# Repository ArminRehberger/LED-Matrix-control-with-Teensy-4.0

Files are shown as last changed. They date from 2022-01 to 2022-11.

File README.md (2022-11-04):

# LEDMatrix-control-with-Teensy-4.0

LED matrix control with Teensy 4.0

Video:  
https://www.youtube.com/watch?v=ZAkksoPda_Q

Functional description:  
FunctionDescriptionLEDMatrix_V1_00.pdf  
FunctionDescriptionLED.pdf  

Implementation of a LED matrix control.
Four LED-Matrix with each 8x32 pixel
Each matrix with 256 pixels, all together 1024 pixel.

Schematic diagram KiCad:


Disclaimer:  
This hardware/software is provided "as is", and you use the hardware/software at your own risk. Under no circumstances shall any author be liable for direct, indirect, special, incidental, or consequential damages resulting from the use, misuse, or inability to use this hardware/software, even if the authors have been advised of the possibility of such damages

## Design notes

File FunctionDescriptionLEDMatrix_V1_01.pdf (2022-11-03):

Function description for LED Matrix, V1.01 2022-11-03, Armin Rehberger

## Table of content

## General description

Implementation of a LED matrix control.
Four LED-Matrix with each 8x32 pixel
Each matrix with 256 pixels, all together 1024 pixel.

Type LED-Matrix: BTF-LIGHTING WS2812BECO https://www.amazon.de/gp/product/B088K1KDW5/ref=ppx_od_dt_b_asin_title_s00?ie=UTF8&psc=1 (https://www.amazon.de/gp/product/B088K1KDW5/ref=ppx_od_dt_b_asin_title_s00?ie=UTF8&psc=1)

## Used hardware

Teensy 4.0

## Used software

Teensy 4.0
Arduino 1.8.15
Teensy Loader 1.54

## Principle structure

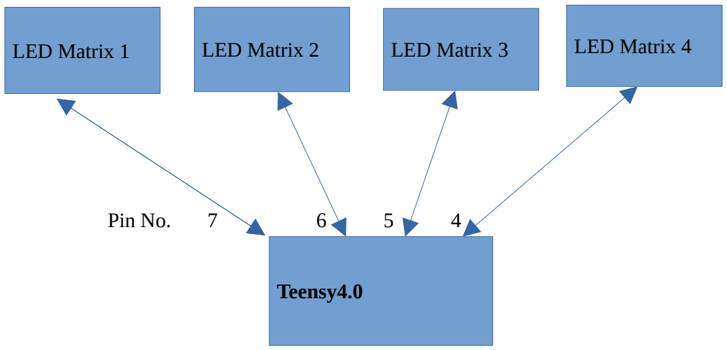
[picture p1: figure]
Pin No.; Teensy4.0; LED Matrix 1; LED Matrix 2; LED Matrix 3; LED Matrix 4

## Used libarys

Libary for LEDs driver: OctoWS2811 https://github.com/PaulStoffregen/OctoWS2811 OctoWS2811.h

Libary for color and shift the LEDs LEDMatrix8.h

## Frequency calculation

Example RGB LED strip with 256LEDs 800Khz = 1.25us
Per bit (high or low): 1.25us
Per LED: 3 Byte = 24 Bit = 30us
Reset: 50us
Per 256 LED: 30us * 256LED = 7680us + 50us = 7730us = 7.73ms Frequency: F=1/t = 1/0.00773s = 129.36Hz

## Software

Already defined letters in function "InitializeLetters" "ABCDEFGHIJKLMNOPQRSTUVWXYZ1234567890!?.:+-=# {}[]" { Haert, part 1
} Haert, part 2
[ Smily, part 1
] Smily, part 2

A string array „char StringToDraw[3][4000]“ must be initialized with the strings to draw. char StringToDraw[3][4000] = {
" [][][][]{}{}{}{} ",
"MERRY CHRISTMAS AND A HAPPY NEW YEAR {}{} ",
"FROHE WEIHNACHTEN UND EIN GUTES NEUES JAHR [][] ", };
The string char array must not exceed 1773 characters.

Scenes
The struct ParaDraw for 100 scenes is foreseen. These struct must be initialized.

ArrayIndexUsed: Must be true, when the scene should be drawen
StringNo: String no. in the StringToDraw array to be drawen
DelaytimeMillis: Delaytime in ms to shift the pixel array e.g. 10, 20, 25, 50, 100, 2000, 0=fastest possible speed
ColorSceneNo: COLOR0, whole matrix one times BLUE, then one times GREEN, then one times RED, ...YELLOW PINK ORANGE WHITE
ColorSceneNo: COLOR1, whole matrix blue MinIntense..MaxIntense..MinIntense, green MinIntense..MaxIntense..MinIntense, red MinIntense..MaxIntense..MinIntense ColorSceneNo: COLOR2, whole matrix in value Color
Color: Used for COLOR2. RED, GREEN, BLUE, YELLOW, PINK, ORANGE, WHITE, BACKGROUNDCOLUR
MaxIntense: Used for Color1, MaxIntense 0..255. MinIntense = 1
AnimationNo: NONE, LEFT, RIGHT, UP, DOWN
AmountNo: Show string x times, e.g. LEFT 7 times

Example:
ParaDraw[Index].ArrayIndexUsed = true; ParaDraw[Index].StringNo = 1; ParaDraw[Index].DelaytimeMillis = 20; ParaDraw[Index].ColorSceneNo = COLOR2; ParaDraw[Index].Color = BLUE; // Just for COLOR2 ParaDraw[Index].MaxIntense = 96; // Just for COLOR1 ParaDraw[Index].AnimationNo = LEFT; ParaDraw[Index].AmountNo = 2;

## Input / Output assignment Teensy 4.0

Pin | Used for
13 | LED buildin
14 | Reserve
15 | Reserve
16 | Reserve
17 | Reserve
18 | SDA0 Reserve
19 | SCL0 Reserve
20 | Reserve
21 | Reserve
22 | Reserve
23 | Reserve
3.3V | Output 250mA (Not connected)
GND 0V Power supply 0V
Vin 5V | Power supply 5V
12 | Reserve
11 | Reserve
10 | Reserve
9 | Reserve
8 | Reserve
7 | LED matrix 1 (Output)
6 | LED matrix 2 (Output)
5 | LED matrix 3 (Output)
4 | LED matrix 4 (Output)
3 | LED matrix 5 (Output)
2 | LED matrix 6 (Output)
1 | LED matrix 7 (Output)
0 | LED matrix 8 (Output)
GND 0V (Not connected)

## KiCad

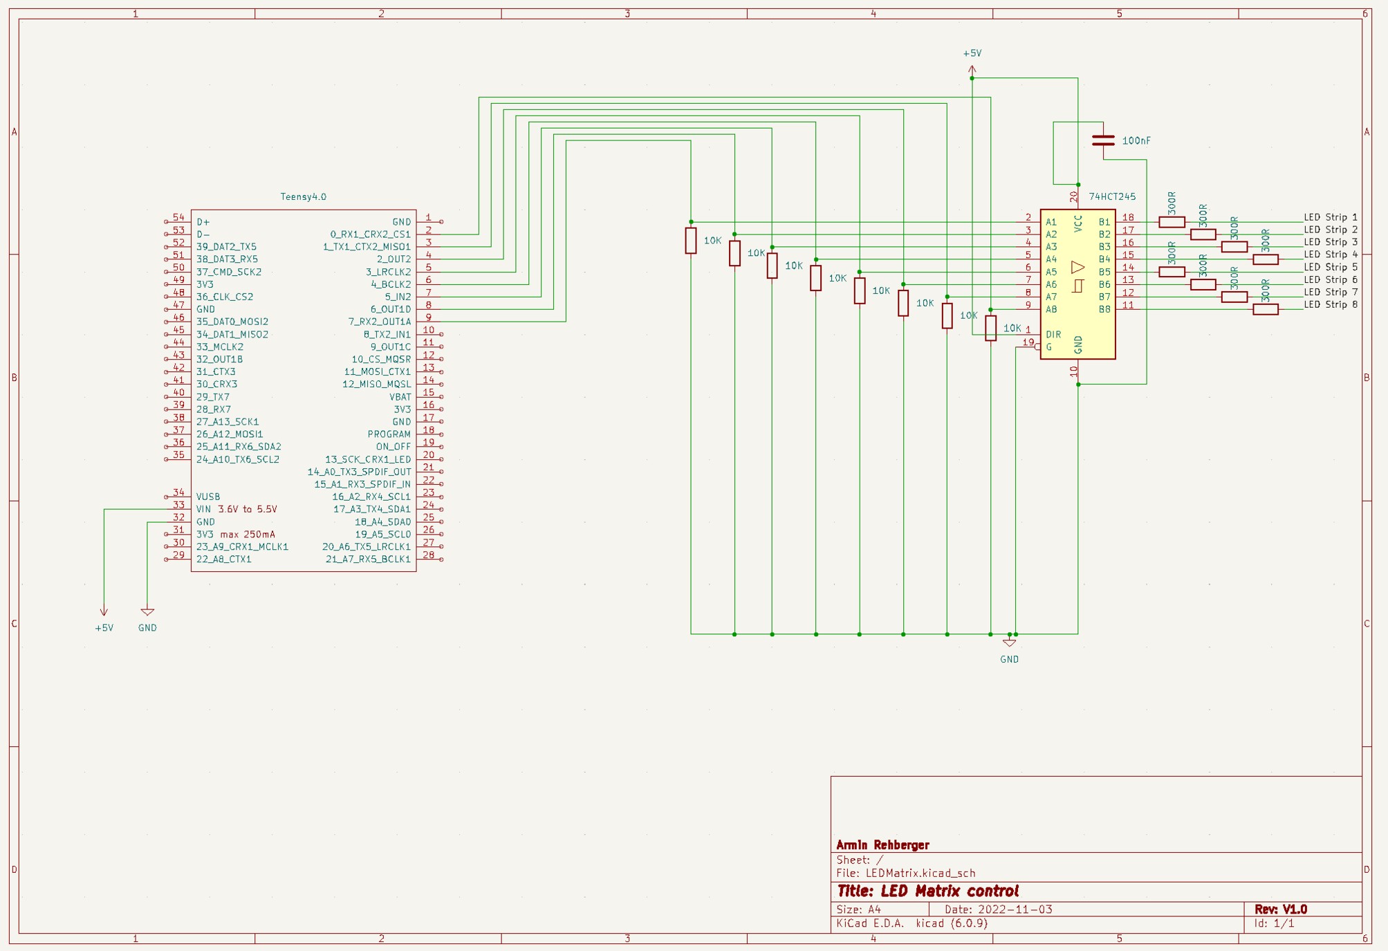
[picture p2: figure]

## Layout circuit board Teensy 4.0

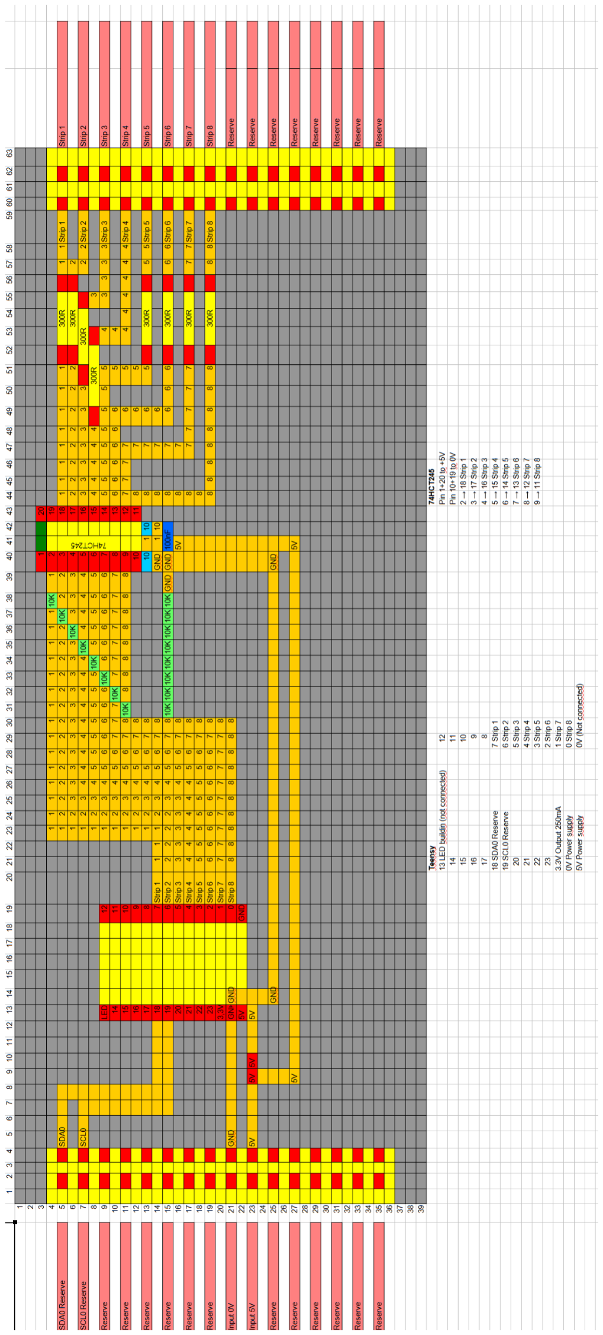
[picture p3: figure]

## Pictures

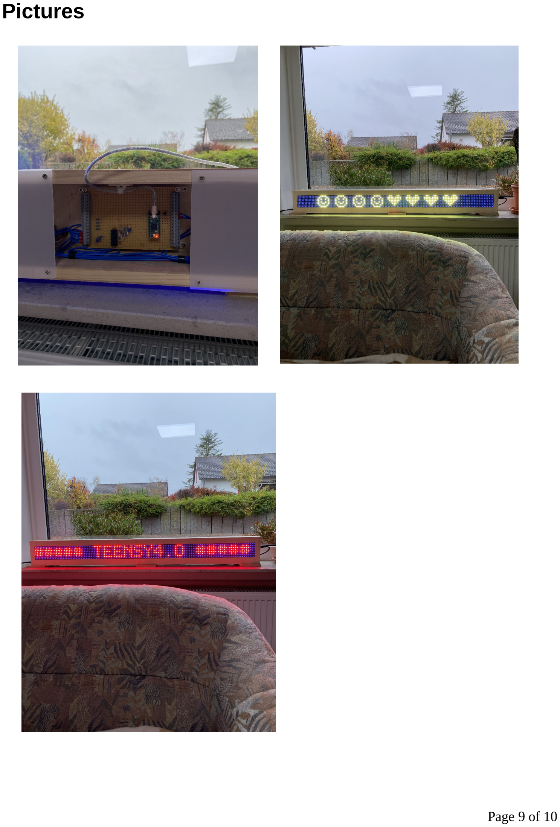
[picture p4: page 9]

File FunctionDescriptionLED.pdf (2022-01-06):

### ProgramFunctions

### Seite 1

byte***drawingLetters; // Three-dimensional array for all letters (level), each letter has 8 line and 6 column (line vertical, column horizontal) void LEDMatrix8::InitializeLetters
First letter
Column → | Example T

← Line

0/0/0 | 0/0/1 | 0/0/2 | 0/0/3 | 0/0/4 | 0/0/5 | 1 | 1 | 1 | 1 | 1 | 0
0/1/0 | 0/1/1 | 0/1/2 | 0/1/3 | 0/1/4 | 0/1/5 | 0 | 0 | 1 | 0 | 0 | 0
0/2/0 | 0/2/1 | 0/2/2 | 0/2/3 | 0/2/4 | 0/2/5 | 0 | 0 | 1 | 0 | 0 | 0
0/3/0 | 0/3/1 | 0/3/2 | 0/3/3 | 0/3/4 | 0/3/5 | 0 | 0 | 1 | 0 | 0 | 0
0/4/0 | 0/4/1 | 0/4/2 | 0/4/3 | 0/4/4 | 0/4/5 | 0 | 0 | 1 | 0 | 0 | 0
0/5/0 | 0/5/1 | 0/5/2 | 0/5/3 | 0/5/4 | 0/5/4 | 0 | 0 | 1 | 0 | 0 | 0
0/6/0 | 0/6/1 | 0/6/2 | 0/6/3 | 0/6/4 | 0/6/5 | 0 | 0 | 1 | 0 | 0 | 0
0/7/0 | 0/7/1 | 0/7/2 | 0/7/3 | 0/7/4 | 0/7/5 | 2 | 2 | 2 | 2 | 2 | 0

Second letter
Column → | Example E

← Line

1/0/0 | 1/0/1 | 1/0/2 | 1/0/3 | 1/0/4 | 0/0/5 | 1 | 1 | 1 | 1 | 1 | 0
1/1/0 | 1/1/1 | 1/1/2 | 1/1/3 | 1/1/4 | 0/1/5 | 1 | 0 | 0 | 0 | 0 | 0
1/2/0 | 1/2/1 | 1/2/2 | 1/2/3 | 1/2/4 | 0/2/5 | 1 | 0 | 0 | 0 | 0 | 0
1/3/0 | 1/3/1 | 1/3/2 | 1/3/3 | 1/3/4 | 0/3/5 | 1 | 1 | 1 | 1 | 0 | 0
1/4/0 | 1/4/1 | 1/4/2 | 1/4/3 | 1/4/4 | 0/4/5 | 1 | 0 | 0 | 0 | 0 | 0
1/5/0 | 1/5/1 | 1/5/2 | 1/5/3 | 1/5/4 | 0/5/4 | 1 | 0 | 0 | 0 | 0 | 0
1/6/0 | 1/6/1 | 1/6/2 | 1/6/3 | 1/6/4 | 0/6/5 | 1 | 1 | 1 | 1 | 1 | 0
1/7/0 | 1/7/1 | 1/7/2 | 1/7/3 | 1/7/4 | 0/7/5 | 2 | 2 | 2 | 2 | 2 | 0

byte**drawingMatrix; // Two dimensional array for all letters, 8 lines and X columns (line vertical, column horizontal) void LEDMatrix8::WriteLetterToDrawingMatrix
Column →
0/0 | 0/1 | 0/2 | 0/3 | 0/4 | 0/5 | 0/6 | 0/7 | 0/8 | 0/9 | 0/10 | 0/11 | 0/12 | 0/13 | 0/14 | 0/15 | 0/16 | 0/17 | 0/18 | 0/19 | 0/20 | 0/21 | 0/22 | 0/23 | 0/24 | 0/25 | 0/26 | 0/27 | 0/28 | 0/29 | 0/30 | 0/31 | 0/32 | 0/33 | 0/34 | 0/35
1/0 | 1/1 | 1/2 | 1/3 | 1/4 | 1/5 | 1/6 | 1/7 | 1/8 | 1/9 | 1/10 | 1/11 | 1/12 | 1/13 | 1/14 | 1/15 | 1/16 | 1/17 | 1/18 | 1/19 | 1/20 | 1/21 | 1/22 | 1/23 | 1/24 | 1/25 | 1/26 | 1/27 | 1/28 | 1/29 | 1/30 | 1/31 | 1/32 | 1/33 | 1/34 | 1/35
2/0 | 2/1 | 2/2 | 2/3 | 2/4 | 2/5 | 2/6 | 2/7 | 2/8 | 2/9 | 2/10 | 2/11 | 2/12 | 2/13 | 2/14 | 2/15 | 2/16 | 2/17 | 2/18 | 2/19 | 2/20 | 2/21 | 2/22 | 2/23 | 2/24 | 2/25 | 2/26 | 2/27 | 2/28 | 2/29 | 2/30 | 2/31 | 2/32 | 2/33 | 2/34 | 2/35
3/0 | 3/1 | 3/2 | 3/3 | 3/4 | 3/5 | 3/6 | 3/7 | 3/8 | 3/9 | 3/10 | 3/11 | 3/12 | 3/13 | 3/14 | 3/15 | 3/16 | 3/17 | 3/18 | 3/19 | 3/20 | 3/21 | 3/22 | 3/23 | 3/24 | 3/25 | 3/26 | 3/27 | 3/28 | 3/29 | 3/30 | 3/31 | 3/32 | 3/33 | 3/34 | 3/35
4/0 | 4/1 | 4/2 | 4/3 | 4/4 | 4/5 | 4/6 | 4/7 | 4/8 | 4/9 | 4/10 | 4/11 | 4/12 | 4/13 | 4/14 | 4/15 | 4/16 | 4/17 | 4/18 | 4/19 | 4/20 | 4/21 | 4/22 | 4/23 | 4/24 | 4/25 | 4/26 | 4/27 | 4/28 | 4/29 | 4/30 | 4/31 | 4/32 | 4/33 | 4/34 | 4/35
5/0 | 5/1 | 5/2 | 5/3 | 5/4 | 5/5 | 5/6 | 5/7 | 5/8 | 5/9 | 5/10 | 5/11 | 5/12 | 5/13 | 5/14 | 5/15 | 5/16 | 5/17 | 5/18 | 5/19 | 5/20 | 5/21 | 5/22 | 5/23 | 5/24 | 5/25 | 5/26 | 5/27 | 5/28 | 5/29 | 5/30 | 5/31 | 5/32 | 5/33 | 5/34 | 5/35
6/0 | 6/1 | 6/2 | 6/3 | 6/4 | 6/5 | 6/6 | 6/7 | 6/8 | 6/9 | 6/10 | 6/11 | 6/12 | 6/13 | 6/14 | 6/15 | 6/16 | 6/17 | 6/18 | 6/19 | 6/20 | 6/21 | 6/22 | 6/23 | 6/24 | 6/25 | 6/26 | 6/27 | 6/28 | 6/29 | 6/30 | 6/31 | 6/32 | 6/33 | 6/34 | 6/35
7/0 | 7/1 | 7/2 | 7/3 | 7/4 | 7/5 | 7/6 | 7/7 | 7/8 | 7/9 | 7/10 | 7/11 | 7/12 | 7/13 | 7/14 | 7/15 | 7/16 | 7/17 | 7/18 | 7/19 | 7/20 | 7/21 | 7/22 | 7/23 | 7/24 | 7/25 | 7/26 | 7/27 | 7/28 | 7/29 | 7/30 | 7/31 | 7/32 | 7/33 | 7/34 | 7/35

← Line

Example TEENSY
Example T
1 | 1 | 1 | 1 | 1 | 0 | 1 | 1 | 1 | 1 | 1 | 0 | 1 | 1 | 1 | 1 | 1 | 0 | 1 | 0 | 0 | 0 | 1 | 0 | 0 | 1 | 1 | 1 | 1 | 0 | 1 | 0 | 0 | 0 | 1 | 0
0 | 0 | 1 | 0 | 0 | 0 | 1 | 0 | 0 | 0 | 0 | 0 | 1 | 0 | 0 | 0 | 0 | 0 | 1 | 1 | 0 | 0 | 1 | 0 | 1 | 0 | 0 | 0 | 0 | 0 | 1 | 0 | 0 | 0 | 1 | 0
0 | 0 | 1 | 0 | 0 | 0 | 1 | 0 | 0 | 0 | 0 | 0 | 1 | 0 | 0 | 0 | 0 | 0 | 1 | 0 | 1 | 0 | 1 | 0 | 1 | 0 | 0 | 0 | 0 | 0 | 0 | 1 | 0 | 1 | 0 | 0
0 | 0 | 1 | 0 | 0 | 0 | 1 | 1 | 1 | 1 | 0 | 0 | 1 | 1 | 1 | 1 | 0 | 0 | 1 | 0 | 0 | 1 | 1 | 0 | 0 | 1 | 1 | 1 | 0 | 0 | 0 | 0 | 1 | 0 | 0 | 0
0 | 0 | 1 | 0 | 0 | 0 | 1 | 0 | 0 | 0 | 0 | 0 | 1 | 0 | 0 | 0 | 0 | 0 | 1 | 0 | 0 | 0 | 1 | 0 | 0 | 0 | 0 | 0 | 1 | 0 | 0 | 0 | 1 | 0 | 0 | 0
0 | 0 | 1 | 0 | 0 | 0 | 1 | 0 | 0 | 0 | 0 | 0 | 1 | 0 | 0 | 0 | 0 | 0 | 1 | 0 | 0 | 0 | 1 | 0 | 0 | 0 | 0 | 0 | 1 | 0 | 0 | 0 | 1 | 0 | 0 | 0
0 | 0 | 1 | 0 | 0 | 0 | 1 | 1 | 1 | 1 | 1 | 0 | 1 | 1 | 1 | 1 | 1 | 0 | 1 | 0 | 0 | 0 | 1 | 0 | 1 | 1 | 1 | 1 | 0 | 0 | 0 | 0 | 1 | 0 | 0 | 0
2 | 2 | 2 | 2 | 2 | 0 | 2 | 2 | 2 | 2 | 2 | 0 | 2 | 2 | 2 | 2 | 2 | 0 | 2 | 2 | 2 | 2 | 2 | 0 | 2 | 2 | 2 | 2 | 2 | 0 | 2 | 2 | 2 | 2 | 2 | 0
byte*drawingArray; | // One-dimensional array with all the pixels of the string

### ProgramFunctions

### Seite 2

void LEDMatrix8::DrawingMatrixToDrawingArray
##### Drawing matrix (Two dimensional array) to drawing array (One dimensional array)

drawingMatrix | Column 0 | Column 1 | Column 2 | Column 3
drawingMatrix | 0/0 | 1/0 | 2/0 | 3/0 | 4/0 | 5/0 | 6/0 | 7/0 | 7/1 | 6/1 | 5/1 | 4/1 | 3/1 | 2/1 | 1/1 | 0/1 | 0/2 | 1/2 | 2/2 | 3/2 | 4/2 | 5/2 | 6/2 | 7/2 | 7/3 | 6/3 | 5/3 | 4/3 | 3/3 | 2/3 | 1/3 | 0/3
drawingArray | 0 | 1 | 2 | 3 | 4 | 5 | 6 | 7 | 8 | 9 | 10 | 11 | 12 | 13 | 14 | 15 | 16 | 17 | 18 | 19 | 20 | 21 | 22 | 23 | 24 | 25 | 26 | 27 | 28 | 29 | 30 | 31
Example T | 1 | 0 | 0 | 0 | 0 | 0 | 0 | 2 | 2 | 0 | 0 | 0 | 0 | 0 | 0 | 1 | 1 | 1 | 1 | 1 | 1 | 1 | 1 | 2 | 2 | 0 | 0 | 0 | 0 | 0 | 0 | 1
drawingMatrix | Column 4 | Column 5
drawingMatrix | 0/4 | 1/4 | 2/4 | 3/4 | 4/4 | 5/4 | 6/4 | 7/4 | 7/5 | 6/5 | 5/5 | 4/5 | 3/5 | 2/5 | 1/5 | 0/5
drawingArray | 32 | 33 | 34 | 35 | 36 | 37 | 38 | 39 | 40 | 41 | 42 | 43 | 44 | 45 | 46 | 47
Example T | 1 | 0 | 0 | 0 | 0 | 0 | 0 | 2 | 2 | 0 | 0 | 0 | 0 | 0 | 0 | 1
Wiring LEDs on matrix | 0 | 15 | 16 | 31 | 32 47
1 | 14 | 17 | 30 | 33 46
2 | 13 | 18 | 29 | 34 45
3 | 12 | 19 | 28 | 35 44
4 | 11 | 20 | 27 | 36 43
5 | 10 | 21 | 26 | 37 42
6 | 9 | 22 | 25 | 38 41
7 | 8 | 23 | 24 | 39 40

void LEDMatrix8::ShiftDrawingArrayRight void LEDMatrix8::ShiftDrawingArrayLeft
void LEDMatrix8::ShiftDrawingArrayUp
void LEDMatrix8::ShiftDrawingArrayDown
These functions shift the array *drawingArray by one column (right, left, up or down).
Then the array length of *DrawPixelArray is copied from the *drawingArray to the *DrawPixelArray

For example shift right one column:
Positions: | 0 → | 15 | 15 → | 16
1 → | 14 | 14 → | 17
2 → | 13 | 13 → | 18
3 → | 12 | 12 → | 19
4 → | 11 | 11 → | 20
5 → | 10 | 10 → | 21
6 → | 9 | 9 → | 22
7 → | 8 | 8 → | 23

byte*DrawPixelArray; // One-dimensional array to be drawen
void DrawPixels
The array *DrawPixelArray is the same as *drawingArray, except the array length. The length of the *drawingArray is the length for all the letters of the string
The length of the *DrawPixelArray is the amount of LEDs
In the function DrawPixels the color of each individual LED is set. For example: Value 0 = BACKGROUNDCOLOR (light blue)
Value 1 = GREEN
Value 2 = RED

### ProgramFunctions

### Seite 3

0/35
1/35
2/35
3/35
4/35
5/35
6/35
7/35

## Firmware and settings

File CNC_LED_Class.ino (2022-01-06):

/*
""" ############################################################################################ """
""" ############################################################################################ """
""" LED matrix (8*X) WS2812B control with Teensy4.0 """
""" V1_00 2022-01-06, Armin Rehberger """
""" ############################################################################################ """
""" ############################################################################################ """
*/

/*
// ###############################################################################################################
// ###############################################################################################################
##### Libary for LEDs driver: OctoWS2811
https://github.com/PaulStoffregen/OctoWS2811
#include <OctoWS2811.h>

##### Libary for color and shift the LEDs
LEDMatrix8.h
Integrated with "", so copy the files LEDMatrix8.cpp and LEDMatrix8.h in the same directory than the file CNC_LED_Class.ino
#include "LEDMatrix8.h"
*/

/*
// ###############################################################################################################
// ###############################################################################################################
Frequency calculation, example RGB LED strip with 300LEDs
800Khz = 1.25us
Per bit (high or low): 1.25us
Per LED: 3 Byte = 24 Bit = 30us
Reset: 50us
Per 300 LED: 30us * 300LED = 9000us + 50us = 9500us = 9.5ms
Frequency: F=1/t = 1/0.0095s = 105.26Hz

Frequency calculation, example RGB LED strip with 256LEDs
800Khz = 1.25us
Per bit (high or low): 1.25us
Per LED: 3 Byte = 24 Bit = 30us
Reset: 50us
Per 256 LED: 30us * 256LED = 7680us + 50us = 7730us = 7.73ms
Frequency: F=1/t = 1/0.00773s = 129.36Hz

Frequency calculation, example RGB LED strip with 125LEDs
800Khz = 1.25us
Per bit (high or low): 1.25us
Per LED: 3 Byte = 24 Bit = 30us
Reset: 50us
Per 125 LED: 30us * 125LED = 3750us + 50us = 3800us = 3.8ms
Frequency: F=1/t = 1/0.0038s = 263.16Hz
*/

/*
// ###############################################################################################################
// ###############################################################################################################
Current calculation
Used voltage: 5V
Per LED 60mA, when all three LEDs are on (color white)
300LEDs  = 18A
2400LEDs = 144A (300LED * 8 stripes)
256LEDs  = 15,36A
1024LEDs = 61.4A (256LED * 4 stripes)
2048LEDs = 122.8A (256LED * 8 stripes)
*/

// ###############################################################################################################
// ###############################################################################################################
// ##### Include
#include <OctoWS2811.h>
#include "LEDMatrix8.h"

// ###############################################################################################################
// ###############################################################################################################
// ##### Common definitions
#define DEBUGMODE true // Print diagnostic values to serial monitor

#define NONE 0
#define LEFT 1
#define RIGHT 2
#define UP 3
#define DOWN 4

#define COLOR0 0
#define COLOR1 1
#define COLOR2 2

// ###############################################################################################################
// ###############################################################################################################
// ##### Global strings to write to the LED matrix
// All together max. 1773 characters

// Already defined letters in function "InitializeLetters"
// "ABCDEFGHIJKLMNOPQRSTUVWXYZ1234567890!?.:+-=# {}[]"
// { Haert, part 1
// } Haert, part 2
// [ Smily, part 1
// ] Smily, part 2

char StringToDraw[3][4000] = {
  "  [][][][]{}{}{}{}   ",
  "MERRY CHRISTMAS AND A HAPPY NEW YEAR {}{} ",
  "FROHE WEIHNACHTEN UND EIN GUTES NEUES JAHR [][] ",
  };

// ###############################################################################################################
// ###############################################################################################################
// ##### Global struct to draw the scenes
typedef struct
{
  bool ArrayIndexUsed;
  int StringNo;
  unsigned long DelaytimeMillis;
  int ColorSceneNo;
  int Color;
  int MaxIntense;
  int AnimationNo;
  int AmountNo;
} ParameterDrawScene;
ParameterDrawScene ParaDraw[100] = {};

// ###############################################################################################################
// ###############################################################################################################
// ##### Forward declaration functions
bool DrawScene(ParameterDrawScene*, const char*, int);
void DrawPixels(int, const byte[], unsigned long);

// ###############################################################################################################
// ###############################################################################################################
// ##### Initialize scenes
// LED-Matrix will start with scene 0, 1, ... After last scene, it starts again with scene 0

// ArrayIndexUsed: Must be true, when the scene should be drawen
// StringNo: String no. in the StringToDraw array to be drawen
// DelaytimeMillis: Delaytime in ms to shift the pixel array e.g. 10, 20, 25, 50, 100, 2000, 0=fastest possible speed
// ColorSceneNo: COLOR0, whole matrix one times BLUE, then one times GREEN, then one times RED, ...YELLOW PINK ORANGE WHITE
// ColorSceneNo: COLOR1, whole matrix blue MinIntense..MaxIntense..MinIntense, green MinIntense..MaxIntense..MinIntense, red MinIntense..MaxIntense..MinIntense
// ColorSceneNo: COLOR2, whole matrix in value Color
// Color: Used for COLOR2. RED, GREEN, BLUE, YELLOW, PINK, ORANGE, WHITE, BACKGROUNDCOLUR
// MaxIntense: Used for Color1, MaxIntense 0..255. MinIntense = 1
// AnimationNo: NONE, LEFT, RIGHT, UP, DOWN
// AmountNo: Show string x times, e.g. LEFT 7 times

void InitValuesForScenes()
{
  // ##### Local variables
  int Index = 0;

  // ##### Scene 0, String no. 1, COLOR0
  ParaDraw[Index].ArrayIndexUsed = true;
  ParaDraw[Index].StringNo = 1;
  ParaDraw[Index].DelaytimeMillis = 20;
  ParaDraw[Index].ColorSceneNo = COLOR0;
  ParaDraw[Index].Color = PINK; // Just for COLOR2
  ParaDraw[Index].MaxIntense = 96; // Just for COLOR1
  ParaDraw[Index].AnimationNo = LEFT;
  ParaDraw[Index].AmountNo = 7;
  Index++;

  // ##### Scene 1, String no. 1, COLOR1
  ParaDraw[Index].ArrayIndexUsed = true;
  ParaDraw[Index].StringNo = 1;
  ParaDraw[Index].DelaytimeMillis = 20;
  ParaDraw[Index].ColorSceneNo = COLOR1;
  ParaDraw[Index].Color = PINK; // Just for COLOR2
  ParaDraw[Index].MaxIntense = 96; // Just for COLOR1
  ParaDraw[Index].AnimationNo = LEFT;
  ParaDraw[Index].AmountNo = 5;
  Index++;

  // ##### Scene 2, String no. 1, COLOR2
  ParaDraw[Index].ArrayIndexUsed = true;
  ParaDraw[Index].StringNo = 1;
  ParaDraw[Index].DelaytimeMillis = 20;
  ParaDraw[Index].ColorSceneNo = COLOR2;
  ParaDraw[Index].Color = BLUE; // Just for COLOR2
  ParaDraw[Index].MaxIntense = 96; // Just for COLOR1
  ParaDraw[Index].AnimationNo = LEFT;
  ParaDraw[Index].AmountNo = 2;
  Index++;

  // ##### Scene 3, String no. 2, COLOR2
  ParaDraw[Index].ArrayIndexUsed = true;
  ParaDraw[Index].StringNo = 2;
  ParaDraw[Index].DelaytimeMillis = 20;
  ParaDraw[Index].ColorSceneNo = COLOR2;
  ParaDraw[Index].Color = ORANGE; // Just for COLOR2
  ParaDraw[Index].MaxIntense = 96; // Just for COLOR1
  ParaDraw[Index].AnimationNo = RIGHT;
  ParaDraw[Index].AmountNo = 1;
  Index++;

  // ##### Scene 4, String no. 0, COLOR2
  ParaDraw[Index].ArrayIndexUsed = true;
  ParaDraw[Index].StringNo = 0;
  ParaDraw[Index].DelaytimeMillis = 20;
  ParaDraw[Index].ColorSceneNo = COLOR2;
  ParaDraw[Index].Color = YELLOW; // Just for COLOR2
  ParaDraw[Index].MaxIntense = 96; // Just for COLOR1
  ParaDraw[Index].AnimationNo = UP;
  ParaDraw[Index].AmountNo = 1;
  Index++;

  // ##### Scene 5, String no. 0, COLOR2
  ParaDraw[Index].ArrayIndexUsed = true;
  ParaDraw[Index].StringNo = 0;
  ParaDraw[Index].DelaytimeMillis = 20;
  ParaDraw[Index].ColorSceneNo = COLOR2;
  ParaDraw[Index].Color = PINK; // Just for COLOR2
  ParaDraw[Index].MaxIntense = 96; // Just for COLOR1
  ParaDraw[Index].AnimationNo = DOWN;
  ParaDraw[Index].AmountNo = 1;
  Index++;
 
  // ##### Scene 6, String no. 0, COLOR2
  ParaDraw[Index].ArrayIndexUsed = true;
  ParaDraw[Index].StringNo = 0;
  ParaDraw[Index].DelaytimeMillis = 20;
  ParaDraw[Index].ColorSceneNo = COLOR2;
  ParaDraw[Index].Color = WHITE; // Just for COLOR2
  ParaDraw[Index].MaxIntense = 96; // Just for COLOR1
  ParaDraw[Index].AnimationNo = NONE;
  ParaDraw[Index].AmountNo = 10;
  Index++;
}

// ###############################################################################################################
// ###############################################################################################################
// ##### Create and configure an OctoWS2811 object
// The total number of pixels is "ledsPerStrip * numPins"
const int ledsPerStrip = 256; // LED-matrix 8x32
const int numPins = 4; // Amount of conected output pins, 1, 2, 3, 4, ... 8
byte pinList[numPins] = {7, 6, 5, 4}; // Connected output pin numbers. With Teensy 4.x, you can use any group of pins.
const int bytesPerLED = 3;  // RGB 3 bytes needed, RGBW 4 bytes needed
DMAMEM int displayMemory[ledsPerStrip * numPins * bytesPerLED / 4]; // Allocate DMA memory Teensy4 DMAChannel.h. Divide by 4 int -> byte
int drawingMemory[ledsPerStrip * numPins * bytesPerLED / 4];

const int config = WS2811_GRB | WS2811_800kHz; // LED Matrix WS2811_GRB, LED stripe WS2811_RGB
OctoWS2811 leds(ledsPerStrip, displayMemory, drawingMemory, config, numPins, pinList);

// ###############################################################################################################
// ###############################################################################################################
// ##### Create and configure an LED matrix object
int AmountOfStrings;    // Amount of strings in the StringToDraw char-array
int AmountOfIndex;      // Amount of index in the ParaDraw array
int ActiveIndex = 0;
const int AmountOfPixelsDrawingArray = ledsPerStrip * numPins;
LEDMatrix8 matrix(StringToDraw, AmountOfPixelsDrawingArray, ActiveIndex); // String array, amount of pixels, active string no.

// ###############################################################################################################
// ###############################################################################################################
// ##### Initialization setup()
void setup()
{

  // ##### Define LED on board
  pinMode(LED_BUILTIN, OUTPUT); // LED on board

  // ##### Serieller Monitor
  if (DEBUGMODE == true)
  {
    Serial.begin(9600);
    Serial.println("Startup");
  }

  // ##### Start OctoWS2811
  leds.begin();
  leds.show();

  // ##### Initialize values for scenes
  InitValuesForScenes();

  // ##### Get amount of strings in the StringToDraw char-array
  AmountOfStrings = sizeof StringToDraw / sizeof *StringToDraw;
  // ##### Get amount of index in the ParaDraw array
  AmountOfIndex = sizeof ParaDraw / sizeof *ParaDraw;

  // ##### Check if in first scene string no. != 0, because matrix is initialized with string no. 0
  // If so, initialize scene again
  if(ParaDraw[ActiveIndex].StringNo != 0)
  {
      if(ParaDraw[ActiveIndex].StringNo >= AmountOfStrings)
      {
        ParaDraw[ActiveIndex].StringNo = 0;
      }
      matrix.InitSzene(REDRAW, ParaDraw[ActiveIndex].StringNo);
  }

} // void setup()

// ###############################################################################################################
// ###############################################################################################################
// ##### Main program loop()
void loop()
{
  // ##### Local variables
  static bool ledon = false;
  static int SceneNo = 0;
  int StringNoOld, StringNoNew;
  bool SceneDone;

  // ##### Draw scene
  switch(SceneNo)
  {
    // ##### Draw scene
    case 0:
      if(ParaDraw[ActiveIndex].ArrayIndexUsed == true)
      {
        // Call function draw scene
        SceneDone = DrawScene(&ParaDraw[ActiveIndex], StringToDraw[ParaDraw[ActiveIndex].StringNo], AmountOfPixelsDrawingArray);
        if(SceneDone == true)
        {
          SceneNo++;
        }        
      }
      else
      {
        SceneNo++;
      }
      break;

    // ##### Increment index, check if string no. has changed
    case 1:
      StringNoOld = ParaDraw[ActiveIndex].StringNo;
      ActiveIndex++;
      if(ActiveIndex > AmountOfIndex-1)
      {
        ActiveIndex = 0;
      }
      StringNoNew = ParaDraw[ActiveIndex].StringNo;
      if(StringNoOld == StringNoNew)
      {
        SceneNo = 0;
      }
      else
      {
        SceneNo++;
      }
      break;

    // ##### Initialize scene, if string no. has changed
    case 2:
      if(ParaDraw[ActiveIndex].StringNo >= AmountOfStrings)
      {
        ParaDraw[ActiveIndex].StringNo = 0;
      }
      matrix.InitSzene(REDRAW, ParaDraw[ActiveIndex].StringNo);
      SceneNo = 0;
      break;

    default:
    break;   
  }

  // ##### Toggle LED on board
  ledon = ! ledon;
  digitalWrite(LED_BUILTIN, ledon);
} // void loop()

// ###############################################################################################################
// ###############################################################################################################
// ##### Draw scene
bool DrawScene(ParameterDrawScene *inParaDraw, const char* inStringToDraw, int inAmountOfPixelsDrawingArray)
{
  // ##### Local variables
  bool ReturnDone = false;
  static int StrlenActiveString;
  static int ColumnsActiveString;
  static int CounterActiveScene = 0;
  static int AmountActiveScene = 0;

  StrlenActiveString = strlen(inStringToDraw);
  ColumnsActiveString = StrlenActiveString * AMOUNTCOLUMNLETTER;

  // ##### Color scene
  switch(inParaDraw->ColorSceneNo)
  {
    case COLOR0:
      matrix.ColorScene0(ColumnsActiveString); // ColorScene 0, whole matrix inparameter times BLUE, then inparameter times GREEN, then inparameter times RED, ...YELLOW PINK ORANGE WHITE
    break;
    case COLOR1:
      matrix.ColorScene1(inParaDraw->MaxIntense); // ColorScene 1, whole matrix blue 1..inParaDraw->MaxIntense..1, green 1..inParaDraw->MaxIntense..1, red 1..inParaDraw->MaxIntense..1
    break;
    case COLOR2:
      matrix.ColorScene2(inParaDraw->Color); // ColorScene 2, whole matrix inParaDraw->Color
    break;
    default:
      matrix.ColorScene2(inParaDraw->Color); // ColorScene 2, whole matrix inParaDraw->Color
    break;   
  }

  // ##### Draw scene
  DrawPixels(inAmountOfPixelsDrawingArray, matrix.DrawPixelArray, inParaDraw->DelaytimeMillis);

  // ##### Animation scene (shift left, right, up, down)
  switch(inParaDraw->AnimationNo)
  {
    case NONE:
      AmountActiveScene = AMOUNTLINESLETTER * inParaDraw->AmountNo;
    break;
    case LEFT:
      matrix.ShiftDrawingArrayLeft();
      AmountActiveScene = ColumnsActiveString * inParaDraw->AmountNo;
    break;
    case RIGHT:
      matrix.ShiftDrawingArrayRight();
      AmountActiveScene = ColumnsActiveString * inParaDraw->AmountNo;
    break;
    case UP:
      matrix.ShiftDrawingArrayUp();
      AmountActiveScene = AMOUNTLINESLETTER * inParaDraw->AmountNo;
    break;
    case DOWN:
      matrix.ShiftDrawingArrayDown();
      AmountActiveScene = AMOUNTLINESLETTER * inParaDraw->AmountNo;
    break;
    default:
      matrix.ShiftDrawingArrayLeft();
      AmountActiveScene = ColumnsActiveString * inParaDraw->AmountNo;
    break;   
  }

  // ##### Scene done
  CounterActiveScene++;
  if(CounterActiveScene >= AmountActiveScene) // Show string x times
  {
    DrawPixels(inAmountOfPixelsDrawingArray, matrix.DrawPixelArray, 1000); // Draw scene and wait 1000ms
    CounterActiveScene = 0;
    ReturnDone = true;
  }

  return ReturnDone;
}

// ###############################################################################################################
// ###############################################################################################################
// ##### Draw the pixels
void DrawPixels(int inAmountOfPixelsDrawingArray, const byte inDrawPixelArray[], unsigned long inDelaytimeMillis)
{
  // ##### Local variables
  static unsigned long previousMillis = 0;
  static unsigned long currentMillis = 0;
  bool LEDbusy;
  int ColorPixel;
  int i;

  // ##### Set the pixels color
  for (i=0; i < inAmountOfPixelsDrawingArray; i++)
  {
    if(inDrawPixelArray[i] == 0) // 0 = pixel for background
    {
      ColorPixel = BACKGROUNDCOLUR;
    }
    else if(inDrawPixelArray[i] == 1) // 1 = pixel for letter / number
    {
      ColorPixel = matrix.ColorPixel[i];
    }
    else if(inDrawPixelArray[i] == 2) // 2 = pixel for underline
    {
      //ColorPixel = RED;
      ColorPixel = BACKGROUNDCOLUR;
      //ColorPixel = matrix.ColorPixel[i];
    }
    else
    {
      ColorPixel = BACKGROUNDCOLUR;
    }
    leds.setPixel(i, ColorPixel); // Set the pixels color
  }

  // ##### Draw the pixels
  leds.show();

  // ##### Delaytime in ms
  if(inDelaytimeMillis != 0)
  {
    currentMillis = millis();
    previousMillis = currentMillis;
    do
    {
      currentMillis = millis();
    } while (currentMillis - previousMillis < inDelaytimeMillis);    
  }
  // ##### Fastest possible speed
  else
  {
    do
    {
      LEDbusy = leds.busy();
    }while (LEDbusy == true);    
  }
}// void DrawPixels
